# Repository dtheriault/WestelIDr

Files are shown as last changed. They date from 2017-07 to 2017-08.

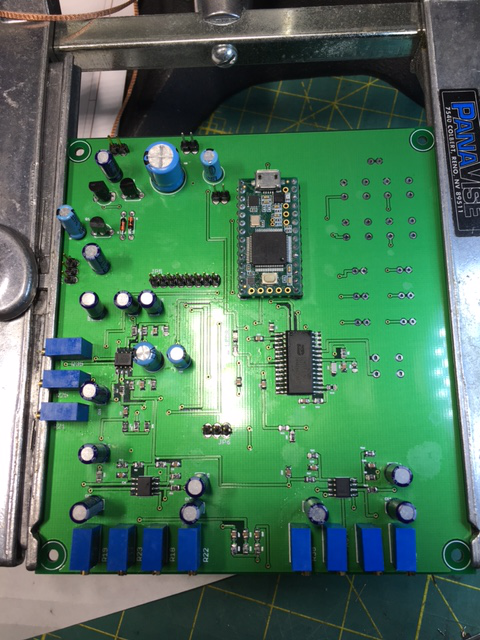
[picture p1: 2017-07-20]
Boards/IMG_1235.JPG

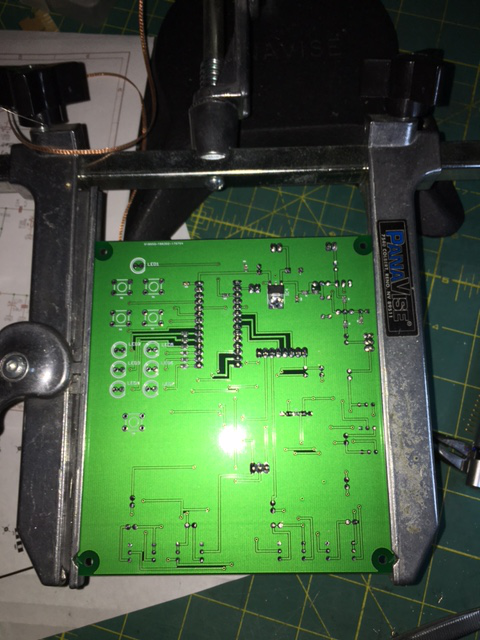
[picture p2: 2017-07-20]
Boards/IMG_1237.JPG

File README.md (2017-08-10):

# WestelIDr
Westel Repeater Controller

This repository contains eagle files and arduino sketch files supporting a repeater
controller based on a Teensy3.2 chip.

The hardware was originally designed to support a Westel DRB25 repeater for WB7NFX
and then updated to support the K7YCA ARES/RACES team who also had one of these
machines.  The controller hardware while supporting the Westel repeater should be
easily modified for other repeater types.  It requires +12v @ approx 150ma, PTT,
Microphone and line audio to generate simple software based carrier detect.

The controller will generate a CW ID or Voice ID in the latest revision of the
sketch file for k7yca.  Can be operated in Ham or Commercial mode with different
timeouts.

Eagle files contain schematics and PCB layout supporting a 3 channel mixer and 3
transistor simplistic audio amplifier to drive a speaker mounted on the Westel
repeater.  There's Gerber files available to spin your own board.

NOTE IMPORTANT:  Current major pin-out issue with the voice ID chip.  I'll update
files and new layout once I fix the darn chip library file.

There's also some mechanical files for a mounting plate for the Westel repeater
which were contributed by Rob KG7LMI.

CW ID code was made possible by SV1DJG and very much appreciated for allowing me to
include his software in the sketch files.

For latest software please refer to the Sketch/k7yca/k7yca.ino file as this version
matches the hardware.  The other two versions were for earlier revisions of the
board for WB7NFX and our Sheriff's Jeep Posse team where I used the controller in
an AmmoCan portable repeater I built for them.

Contact info:

email:  no1d.doug@gmail.com
repository:  https://github.com/dtheriault/WestelIDr

 License:

 Copyright (C) 2017 Douglas Theriault - NO1D

 Software is free software: you can redistribute it and/or modify
 it under the terms of the GNU General Public License as published by
 the Free Software Foundation, either version 3 of the License, or
 (at your option) any later version.

 This is distributed in the hope that it will be useful to someone or ham club/group,
 but WITHOUT ANY WARRANTY; without even the implied warranty of MERCHANTABILITY
 or FITNESS FOR A PARTICULAR PURPOSE.  See the GNU General Public License for
 more details.

 You should have received a copy of the GNU General Public License
 in the repository.  If not, see <http://www.gnu.org/licenses/>.

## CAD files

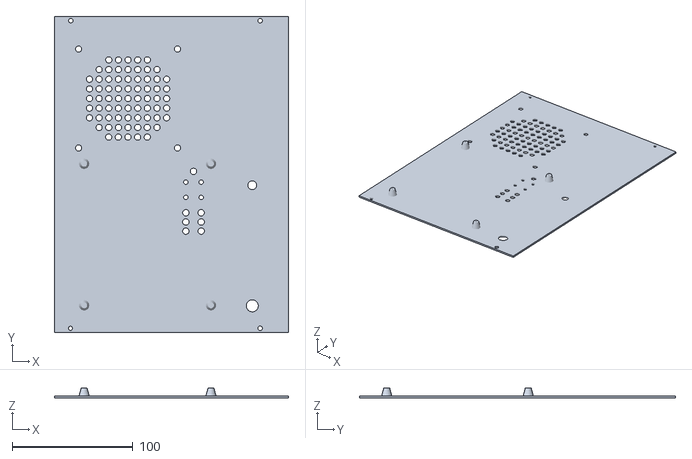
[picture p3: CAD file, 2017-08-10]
Faceplate/westel faceplate 0.9.4.stl
194.0 x 262.0 x 8.00

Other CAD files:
Faceplate/westel faceplate 0.9.4.skp

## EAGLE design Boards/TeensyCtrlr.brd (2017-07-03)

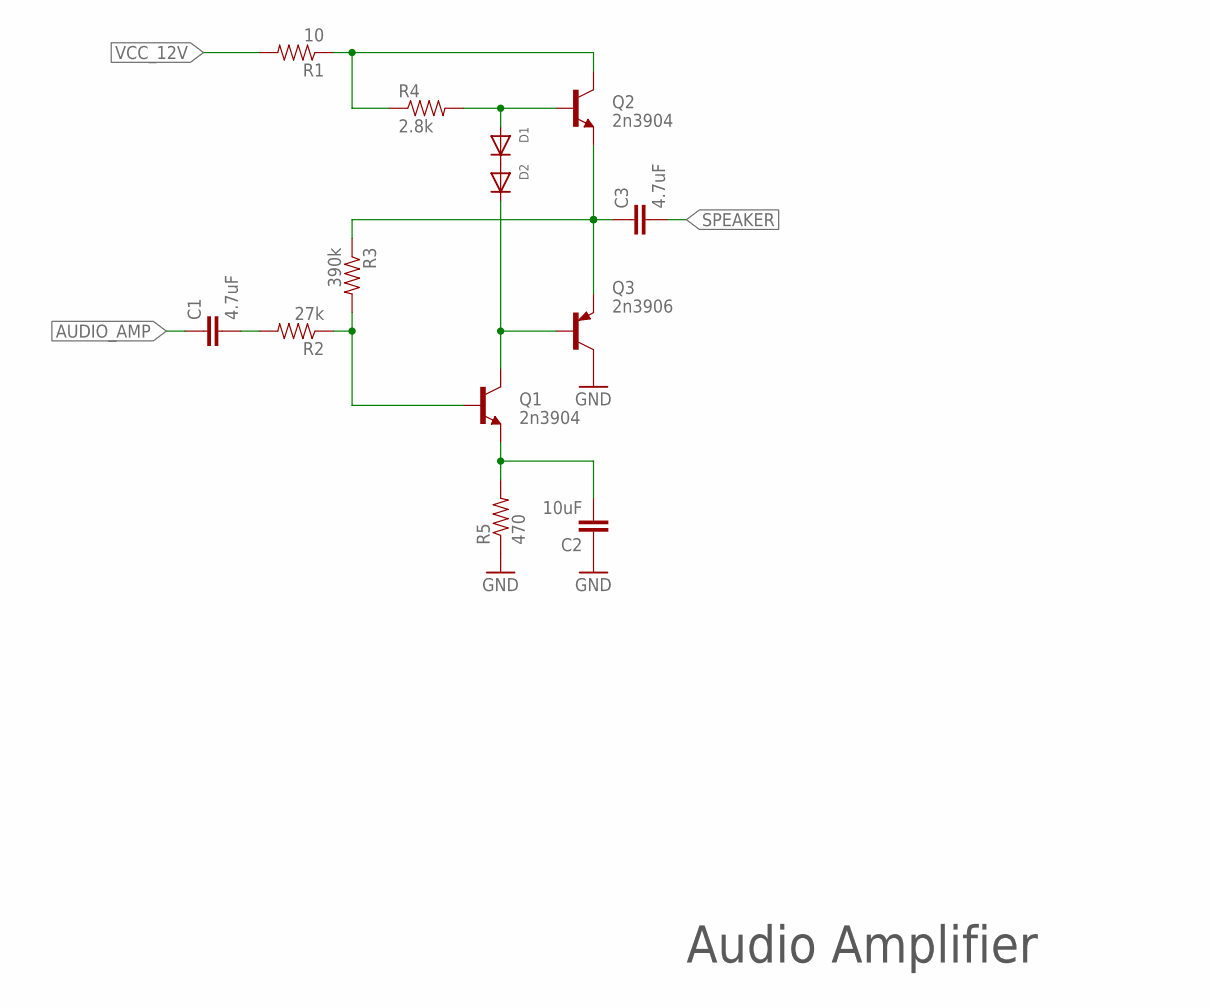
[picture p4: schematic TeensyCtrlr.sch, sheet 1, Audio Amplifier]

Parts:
C1, C3: 4.7uF; CAP-PTH-SMALL
C2: 10uF; CAP-PTH-SMALL
D1, D2: DIODEDO-1N4148; DO-1N4148
Q1, Q2: 2n3904; TO-92-AMMO
Q3: 2n3906; TO92-EBC
R1: 10; 0805
R2: 27k; 0805
R3: 390k; 0805
R4: 2.8k; 0805
R5: 470; 0805

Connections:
AUDIO_AMP: C1.1; also elsewhere on the board
GND: C2.1, Q3.C, R5.1; also elsewhere on the board
unnamed: C1.2, R2.2
unnamed: Q2.3 (C), R1.1, R4.1
unnamed: C2.2, Q1.1 (E), R5.2
unnamed: C3.1, Q2.1 (E), Q3.E, R3.1
unnamed: D1.C, D2.A
unnamed: D1.A, Q2.2 (B), R4.2
unnamed: D2.C, Q1.3 (C), Q3.B
unnamed: Q1.2 (B), R2.1, R3.2
SPEAKER: C3.2; also elsewhere on the board
VCC_12V: R1.2; also elsewhere on the board

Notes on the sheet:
Audio Amplifier

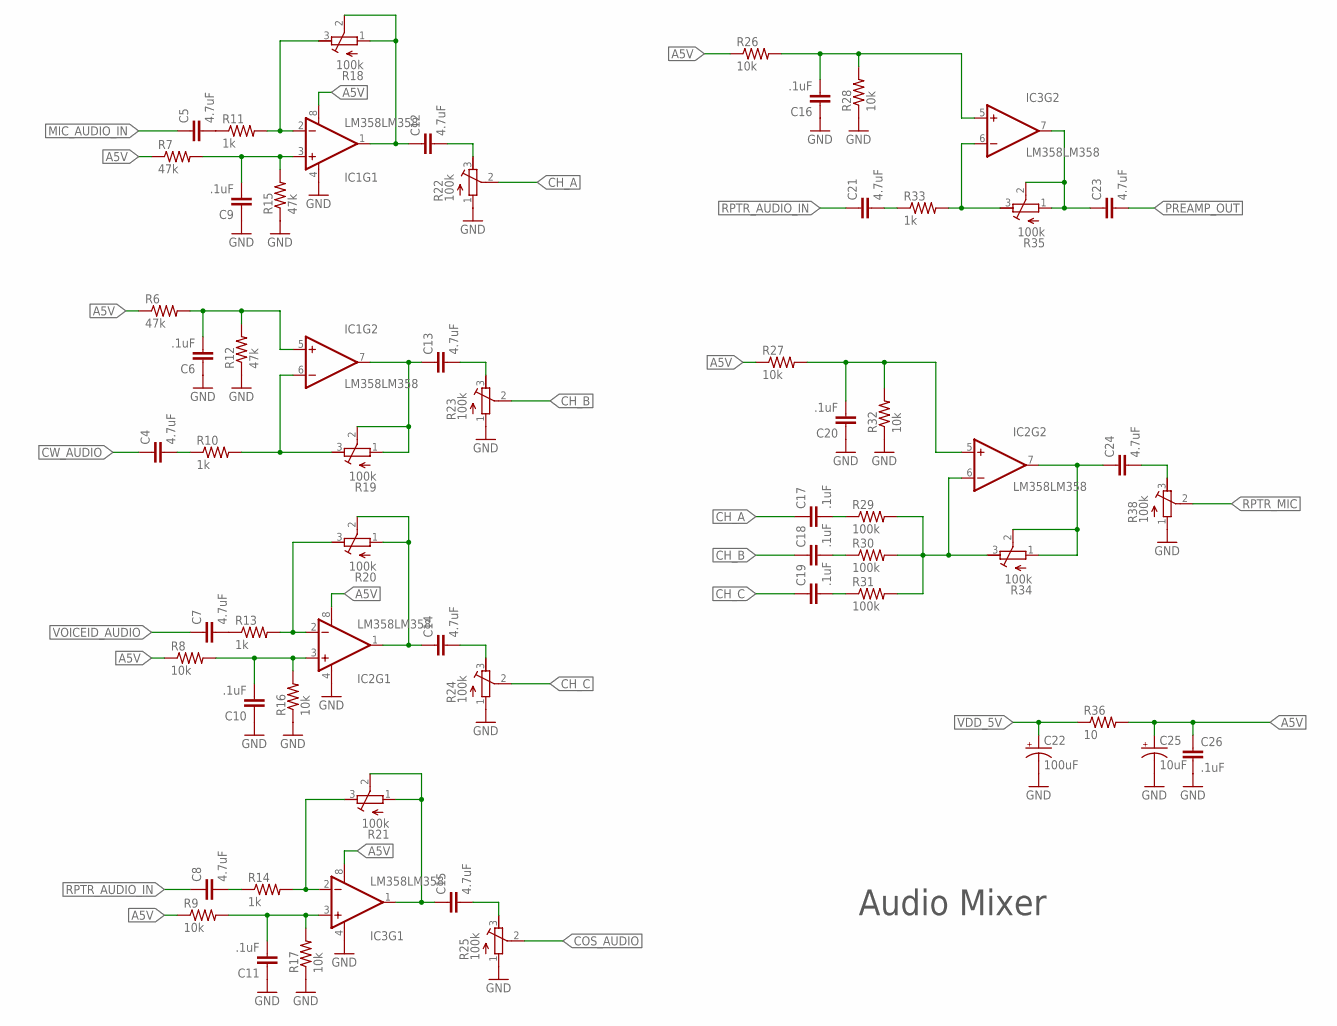
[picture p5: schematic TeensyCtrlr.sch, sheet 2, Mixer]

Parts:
C4, C5, C7, C8, C12, C13, C14, C15, C21, C23, C24: 4.7uF; CAP-PTH-SMALL2
C6, C9, C10, C11, C16, C17, C18, C19, C20, C26: .1uF; 0805
C22: 100uF; CPOL-RADIAL-10UF-25V
C25: 10uF; CPOL-RADIAL-100UF-25V
IC1, IC2, IC3: LM358LM358; SOIC8
R6, R7, R12, R15: 47k; 0805
R8, R9, R16, R17, R26, R27, R28, R32: 10k; 0805
R10, R11, R13, R14, R33: 1k; 0805
R18, R19, R20, R21, R22, R23, R24, R25, R34, R35, R38: 100k; RTRIM3296X
R29, R30, R31: 100k; 0805
R36: 10; 0805

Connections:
A5V: C25.1 (+), C26.1, IC1.8 (V+), IC2.8 (V+), IC3.8 (V+), R6.1, R7.1, R8.1, R9.1, R26.1, R27.1, R36.2
CH_A: C17.1, R22.2 (S)
CH_B: C18.1, R23.2 (S)
CH_C: C19.1, R24.2 (S)
COS_AUDIO: R25.2 (S); also elsewhere on the board
CW_AUDIO: C4.1; also elsewhere on the board
GND: C6.1, C9.1, C10.1, C11.1, C16.1, C20.1, C22.2 (-), C25.2 (-), C26.2, IC1.4 (V-), IC2.4 (V-), IC3.4 (V-), R12.1, R15.1, R16.1, R17.1, R22.1 (A), R23.1 (A), R24.1 (A), R25.1 (A), R28.1, R32.1, R38.1 (A); also elsewhere on the board
MIC_AUDIO_IN: C5.1; also elsewhere on the board
unnamed: IC1.2 (-IN), R11.2, R18.3 (E)
unnamed: C9.2, IC1.3 (+IN), R7.2, R15.2
unnamed: C5.2, R11.1
unnamed: C12.1, IC1.1 (OUT), R18.1 (A), R18.2 (S)
unnamed: C12.2, R22.3 (E)
unnamed: IC1.6 (-IN), R10.2, R19.3 (E)
unnamed: C6.2, IC1.5 (+IN), R6.2, R12.2
unnamed: C4.2, R10.1
unnamed: C13.1, IC1.7 (OUT), R19.1 (A), R19.2 (S)
unnamed: C13.2, R23.3 (E)
unnamed: IC2.2 (-IN), R13.2, R20.3 (E)
unnamed: C10.2, IC2.3 (+IN), R8.2, R16.2
unnamed: C7.2, R13.1
unnamed: C14.1, IC2.1 (OUT), R20.1 (A), R20.2 (S)
unnamed: C14.2, R24.3 (E)
unnamed: IC2.6 (-IN), R29.2, R30.2, R31.2, R34.3 (E)
unnamed: C20.2, IC2.5 (+IN), R27.2, R32.2
unnamed: C24.1, IC2.7 (OUT), R34.1 (A), R34.2 (S)
unnamed: C24.2, R38.3 (E)
unnamed: IC3.2 (-IN), R14.2, R21.3 (E)
unnamed: C11.2, IC3.3 (+IN), R9.2, R17.2
unnamed: C8.2, R14.1
unnamed: C15.1, IC3.1 (OUT), R21.1 (A), R21.2 (S)
unnamed: C15.2, R25.3 (E)
unnamed: IC3.6 (-IN), R33.2, R35.3 (E)
unnamed: C16.2, IC3.5 (+IN), R26.2, R28.2
unnamed: C21.2, R33.1
unnamed: C23.1, IC3.7 (OUT), R35.1 (A), R35.2 (S)
unnamed: C17.2, R29.1
unnamed: C18.2, R30.1
unnamed: C19.2, R31.1
PREAMP_OUT: C23.2; also elsewhere on the board
RPTR_AUDIO_IN: C8.1, C21.1; also elsewhere on the board
RPTR_MIC: R38.2 (S); also elsewhere on the board
VDD_5V: C22.1 (+), R36.1; also elsewhere on the board
VOICEID_AUDIO: C7.1; also elsewhere on the board

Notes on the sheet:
Audio Mixer

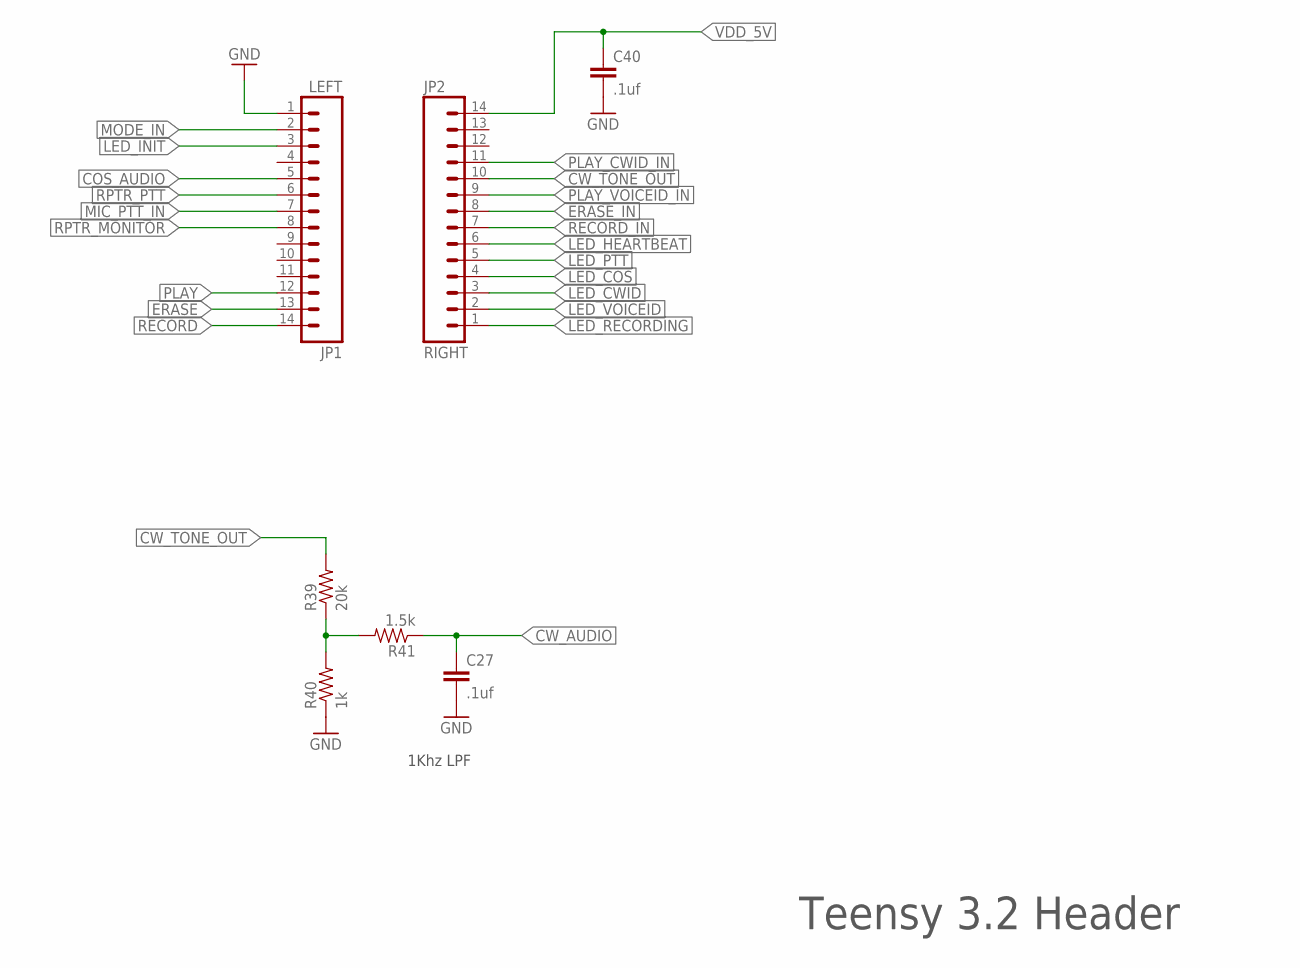
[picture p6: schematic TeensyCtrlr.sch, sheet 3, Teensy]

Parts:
C27, C40: .1uf; 0805
JP1: LEFT; 1X14-LONGPADS
JP2: RIGHT; 1X14-LONGPADS
R39: 20k; 0805
R40: 1k; 0805
R41: 1.5k; 0805

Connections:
COS_AUDIO: JP1.5; also elsewhere on the board
CW_AUDIO: C27.1, R41.1; also elsewhere on the board
CW_TONE_OUT: JP2.10, R39.2
ERASE: JP1.13; also elsewhere on the board
ERASE_IN: JP2.8; also elsewhere on the board
GND: C27.2, C40.2, JP1.1, R40.1; also elsewhere on the board
LED_COS: JP2.4; also elsewhere on the board
LED_CWID: JP2.3; also elsewhere on the board
LED_HEARTBEAT: JP2.6; also elsewhere on the board
LED_INIT: JP1.3; also elsewhere on the board
LED_PTT: JP2.5; also elsewhere on the board
LED_RECORDING: JP2.1; also elsewhere on the board
LED_VOICEID: JP2.2; also elsewhere on the board
MIC_PTT_IN: JP1.7; also elsewhere on the board
MODE_IN: JP1.2; also elsewhere on the board
unnamed: R39.1, R40.2, R41.2
PLAY: JP1.12; also elsewhere on the board
PLAY_CWID_IN: JP2.11; also elsewhere on the board
PLAY_VOICEID_IN: JP2.9; also elsewhere on the board
RECORD: JP1.14; also elsewhere on the board
RECORD_IN: JP2.7; also elsewhere on the board
RPTR_MONITOR: JP1.8; also elsewhere on the board
RPTR_PTT: JP1.6; also elsewhere on the board
VDD_5V: C40.1, JP2.14; also elsewhere on the board

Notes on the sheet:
Teensy 3.2 Header
1Khz LPF

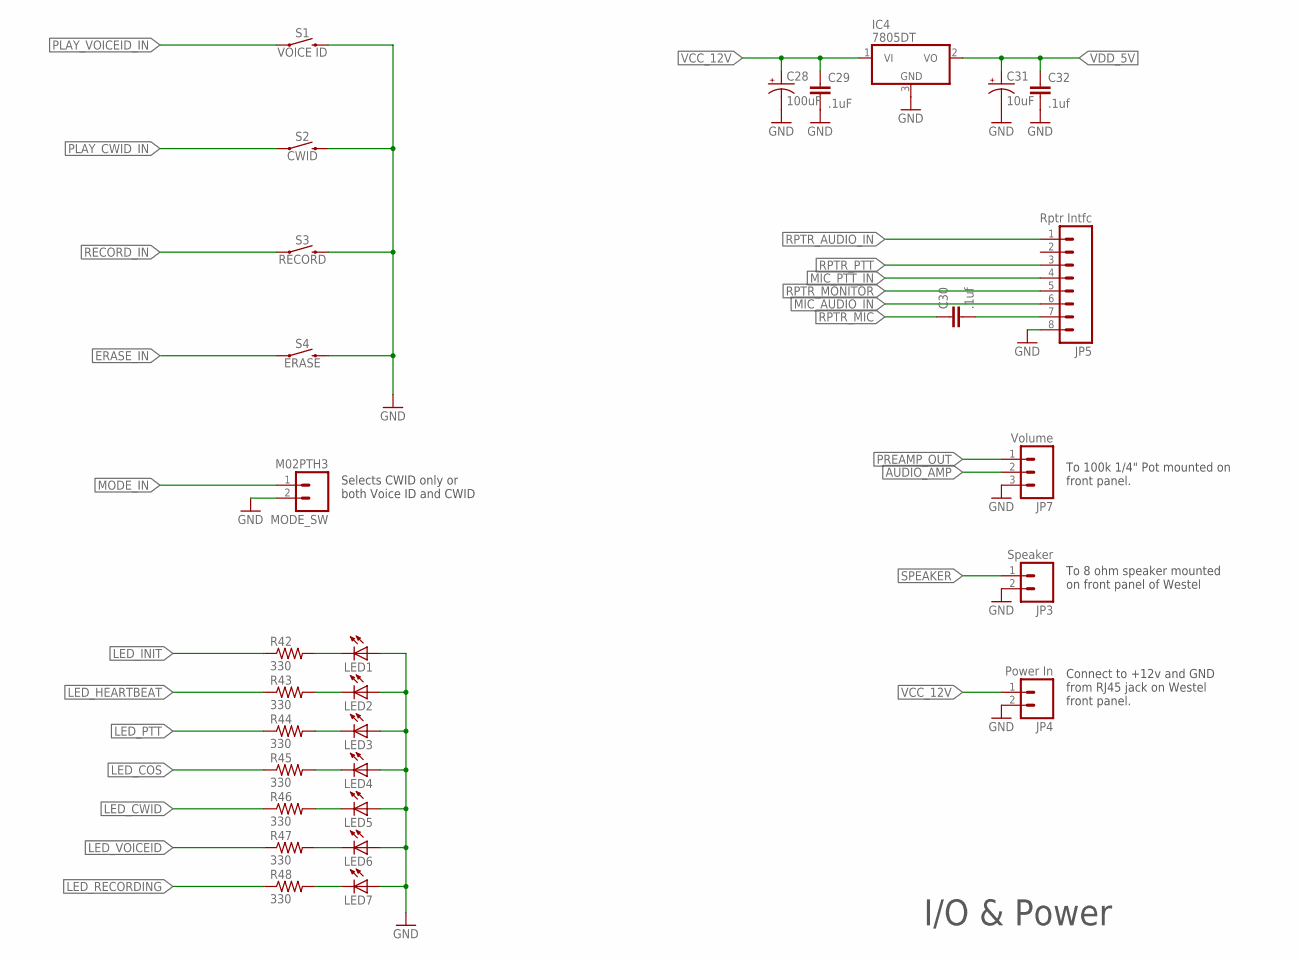
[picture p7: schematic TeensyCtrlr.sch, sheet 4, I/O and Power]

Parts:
C28: 100uF; CPOL-RADIAL-1000UF-25V
C29: .1uF; 0805
C30, C32: .1uf; 0805
C31: 10uF; CPOL-RADIAL-100UF-25V
IC4: 7805DT; TO252
JP3: Speaker; 1X02_LONGPADS
JP4: Power In; 1X02_LONGPADS
JP5: Rptr Intfc; 1X08_LONGPADS
JP7: Volume; 1X03_LONGPADS
LED1, LED2, LED3, LED4, LED5, LED6, LED7: LED5MM
MODE_SW: M02PTH3; 1X02_LONGPADS
R42, R43, R44, R45, R46, R47, R48: 330; 0805
S1: VOICE ID; TACTILE_SWITCH_PTH_6.0MM
S2: CWID; TACTILE_SWITCH_PTH_6.0MM
S3: RECORD; TACTILE_SWITCH_PTH_6.0MM
S4: ERASE; TACTILE_SWITCH_PTH_6.0MM

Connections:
AUDIO_AMP: JP7.2; also elsewhere on the board
ERASE_IN: S4.1; also elsewhere on the board
GND: C28.-, C29.2, C31.2 (-), C32.2, IC4.3 (GND), JP3.2, JP4.2, JP5.8, JP7.3, LED1.A, LED2.A, LED3.A, LED4.A, LED5.A, LED6.A, LED7.A, MODE_SW.2, S1.3 (2), S2.3 (2), S3.3 (2), S4.3 (2); also elsewhere on the board
LED_COS: R45.1; also elsewhere on the board
LED_CWID: R46.1; also elsewhere on the board
LED_HEARTBEAT: R43.1; also elsewhere on the board
LED_INIT: R42.1; also elsewhere on the board
LED_PTT: R44.1; also elsewhere on the board
LED_RECORDING: R48.1; also elsewhere on the board
LED_VOICEID: R47.1; also elsewhere on the board
MIC_AUDIO_IN: JP5.6; also elsewhere on the board
MIC_PTT_IN: JP5.4; also elsewhere on the board
MODE_IN: MODE_SW.1; also elsewhere on the board
unnamed: LED1.K (C), R42.2
unnamed: LED2.K (C), R43.2
unnamed: LED3.K (C), R44.2
unnamed: LED4.K (C), R45.2
unnamed: LED5.K (C), R46.2
unnamed: LED6.K (C), R47.2
unnamed: LED7.K (C), R48.2
unnamed: C30.2, JP5.7
PLAY_CWID_IN: S2.1; also elsewhere on the board
PLAY_VOICEID_IN: S1.1; also elsewhere on the board
PREAMP_OUT: JP7.1; also elsewhere on the board
RECORD_IN: S3.1; also elsewhere on the board
RPTR_AUDIO_IN: JP5.1; also elsewhere on the board
RPTR_MIC: C30.1; also elsewhere on the board
RPTR_MONITOR: JP5.5; also elsewhere on the board
RPTR_PTT: JP5.3; also elsewhere on the board
SPEAKER: JP3.1; also elsewhere on the board
VCC_12V: C28.+, C29.1, IC4.1 (VI), JP4.1; also elsewhere on the board
VDD_5V: C31.1 (+), C32.1, IC4.2 (VO); also elsewhere on the board

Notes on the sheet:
I/O & Power
To 100k 1/4" Pot mounted on front panel.
To 8 ohm speaker mounted on front panel of Westel
Connect to +12v and GND from RJ45 jack on Westel front panel.
Selects CWID only or both Voice ID and CWID

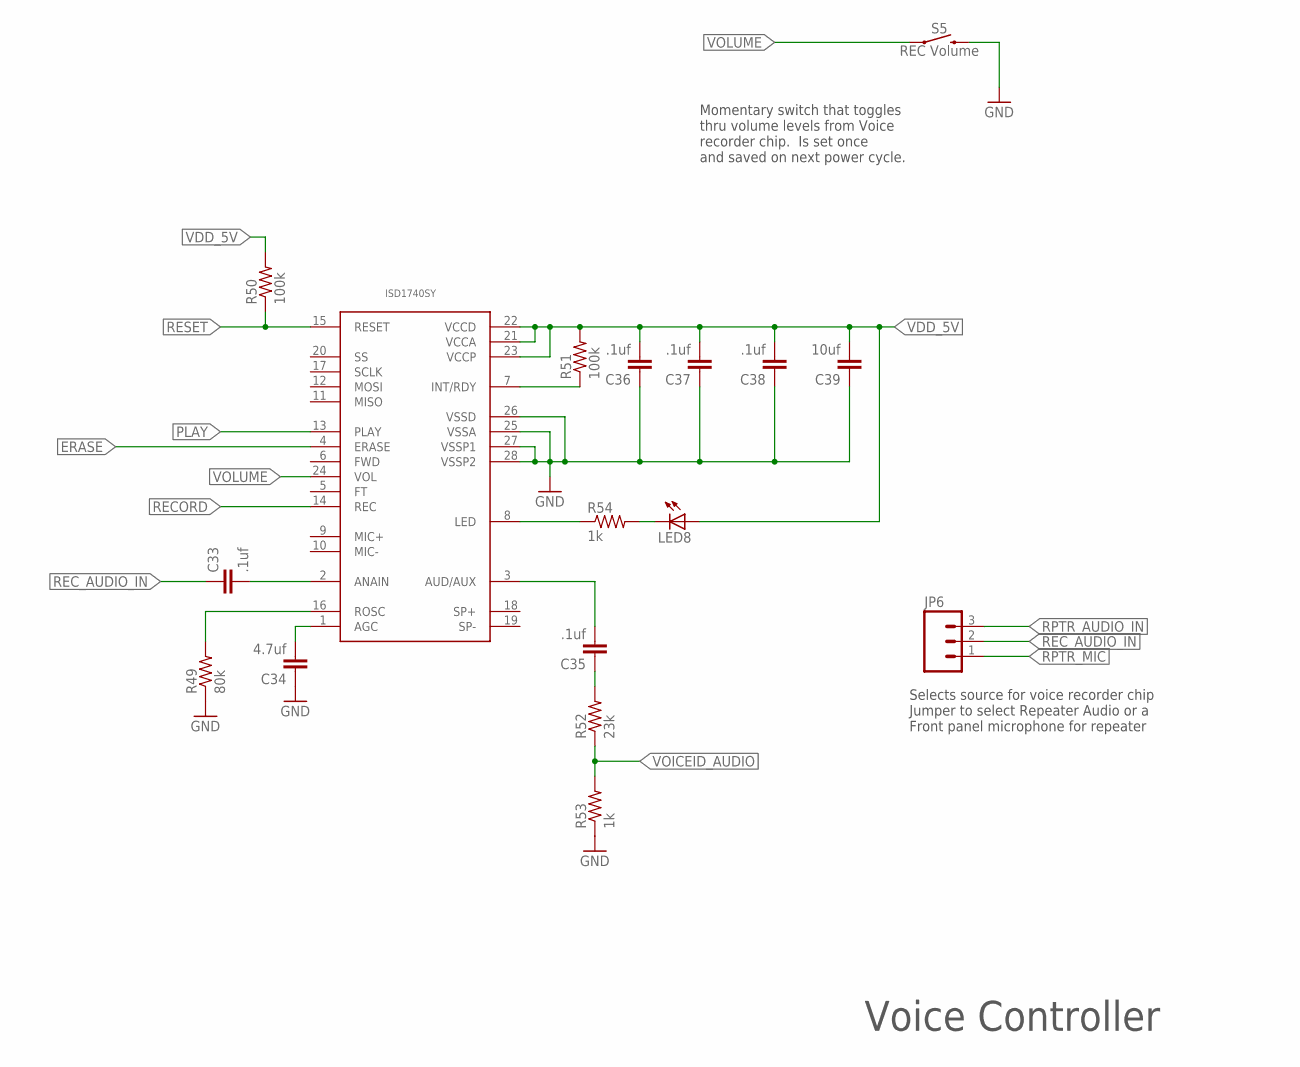
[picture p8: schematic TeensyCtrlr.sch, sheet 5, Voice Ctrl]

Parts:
C33, C35, C36, C37, C38: .1uf; 0805
C34: 4.7uf; 0805
C39: 10uf; 0805
IC$1: ISD1740SYSOIC28; SOIC-28
JP6: M03LONGPADS; 1X03_LONGPADS
LED8: LEDCHIP-LED0805; CHIP-LED0805
R49: 80k; 0805
R50, R51: 100k; 0805
R52: 23k; 0805
R53, R54: 1k; 0805
S5: REC Volume; TACTILE_SWITCH_PTH_6.0MM

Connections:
ERASE: IC$1.4 (ERASE); also elsewhere on the board
GND: C34.1, C36.1, C37.1, C38.1, C39.1, IC$1.25 (VSSA), IC$1.26 (VSSD), IC$1.27 (VSSP1), IC$1.28 (VSSP2), R49.1, R53.1, S5.3 (2); also elsewhere on the board
unnamed: C33.2, IC$1.2 (ANAIN)
unnamed: C35.2, IC$1.3 (AUD/AUX)
unnamed: C35.1, R52.2
unnamed: C34.2, IC$1.1 (AGC)
unnamed: IC$1.16 (ROSC), R49.2
unnamed: IC$1.7 (INT/RDY), R51.1
unnamed: IC$1.8 (LED), R54.1
unnamed: LED8.C, R54.2
PLAY: IC$1.13 (PLAY); also elsewhere on the board
RECORD: IC$1.14 (REC); also elsewhere on the board
REC_AUDIO_IN: C33.1, JP6.2
RESET: IC$1.15 (RESET), R50.1
RPTR_AUDIO_IN: JP6.3; also elsewhere on the board
RPTR_MIC: JP6.1; also elsewhere on the board
VDD_5V: C36.2, C37.2, C38.2, C39.2, IC$1.21 (VCCA), IC$1.22 (VCCD), IC$1.23 (VCCP), LED8.A, R50.2, R51.2; also elsewhere on the board
VOICEID_AUDIO: R52.1, R53.2; also elsewhere on the board
VOLUME: IC$1.24 (VOL), S5.1

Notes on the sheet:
Voice Controller
Selects source for voice recorder chip Jumper to select Repeater Audio or a Front panel microphone for repeater
Momentary switch that toggles thru volume levels from Voice recorder chip. Is set once and saved on next power cycle.

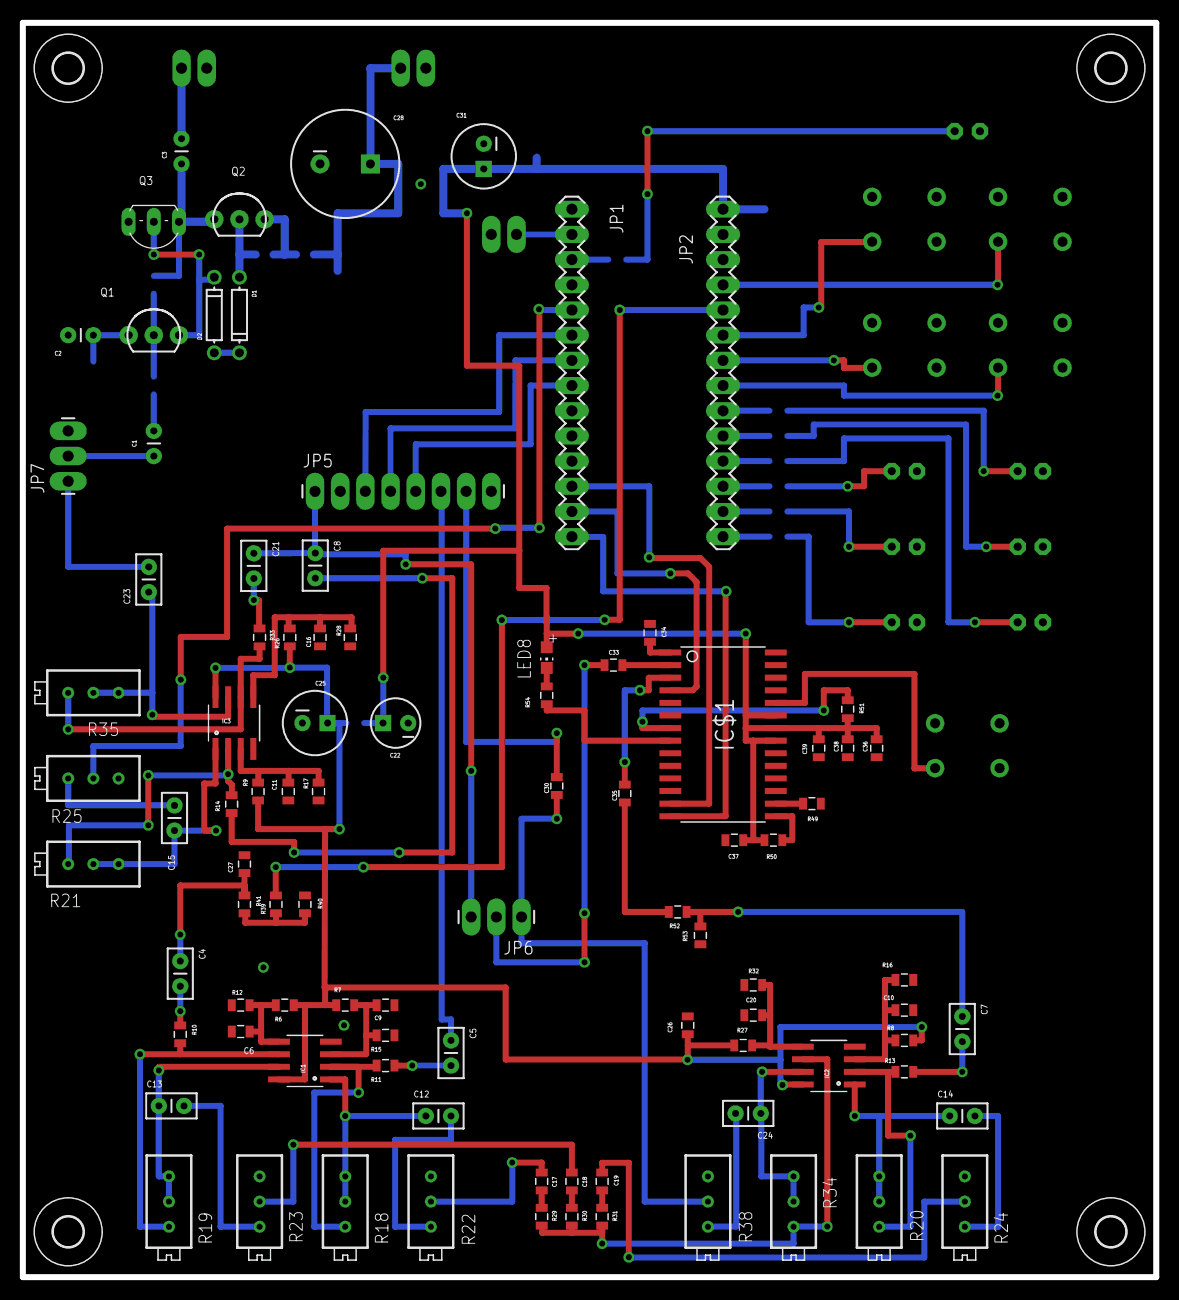
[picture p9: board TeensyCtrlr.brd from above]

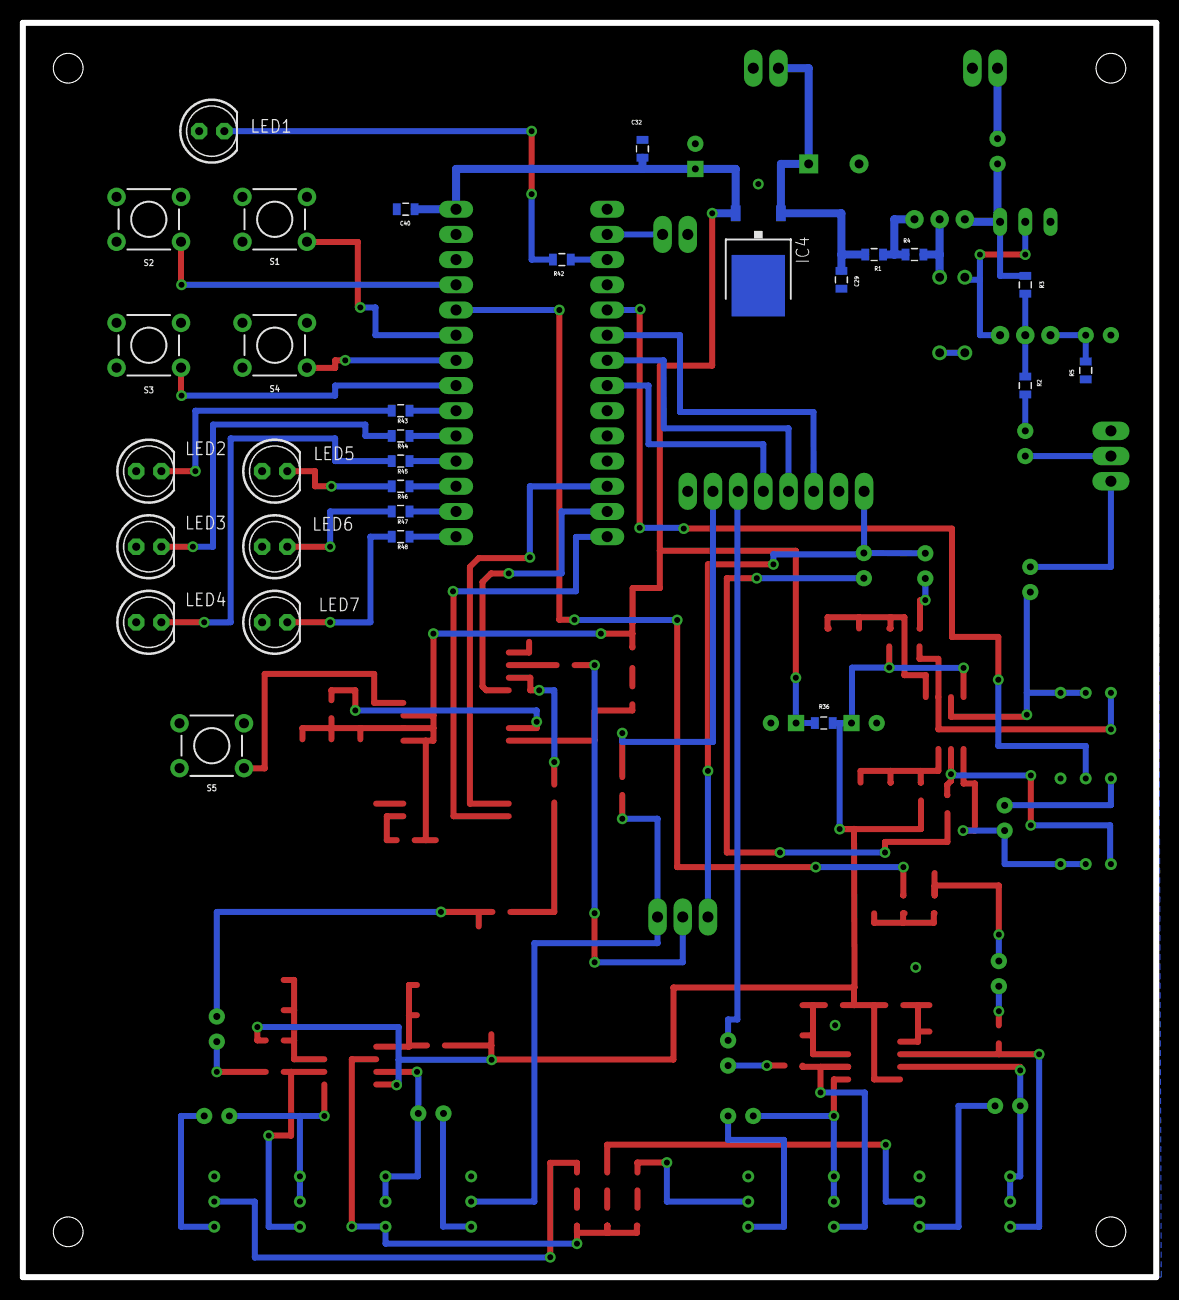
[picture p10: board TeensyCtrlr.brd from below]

Board: 2 copper layers, 114.3 x 126.5 mm, 128 parts (29 on the bottom side), 94 nets.

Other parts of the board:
U$1, U$2, U$3, U$4: 3,0

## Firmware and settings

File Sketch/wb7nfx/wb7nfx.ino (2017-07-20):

//
// File: TeensyRptrCtrlr.ino
//
// Author:  NO1D - Doug Theriault
// Dated:   20170112
//
// Description:
//
// This sketch is a very basic/simple repeater ID controller which was developed
// for WB7NFX.  The interface is to a Westel DRB25 VHF repeater however this
// software is generic and can be modified to fit other requirements.
//
// The software handles button presses to activate CW ID, Voice ID and record
// and erase functions and mode switch.  In addition it outputs series of 7 LEDs
// to track state/function.  It also outputs control lines to a Voice ID board
// and the repeater itself.
//
// Since the Westel Repeater did not have means to detect COS (carrier operated
// squelch) the repeaters audio is fed into a pin configured with ADC so its
// voltage can be read.
//
// The controller was based on Teensy3.2 board.  I started with an ATiny85 but
// quickly ran out of pins as I wanted to add more/more features...
//
// References:
//
// The CW ID portion of the code was developed by SV1DJG which was a great start
// for me to get something working on an ATiny85 chip.  Special thanks goes out
// to Nick for producing this software.  I include his file header below.
//
// Bugs/Issues/ToDo:
//
// Ideally this would all be run off interrupts/timers.  Someday perhaps.
// This is not a very powerful repeater controller.  While it will ID per part 97
// rules, its been deployed only recently and may still contain bugs.
// There are some printf statements for debugging left in the code and do affect
// accuracy of the timing.  You might need to modify delay loops when removing
// them.
//
// Hardware:
//
// Schematic for simple 3-channel audio mixer, 3-transistor audio amp, Teensy I/O
// LED's etc are available on github.
//
// Voice ID is handled by external board similar to:
//   https://ludens.cl/Electron/voiceID/voiceID.html
//
// Contact info:
//
// email:  no1d.doug@gmail.com
// repository:  https://github.com/dtheriault/TeensyRptrCtrlr
//
// License:
//
// Copyright (C) 2017 Douglas Theriault - NO1D
//
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
//
////////////////////////////////////////////////
//
// A simple CW Blinker (aka LED Beacon)
// by SV1DJG (c.2016)
//
// This is a ultra simple blinker in CW for the 
// digispark mini board (attiny85).
// change the led port if using a different
// board (e.g. Arduino)
//
// Just set your message into the msg array and you 
// are ready to go.Make sure to use ONLY the set
// of the supported characters.
// the supported set of characters is capital 
// letters,numbers and a few symbols.
//
// You can also modify the transmission speed by 
// changing the speedWPM variable.
//
// HAVE FUN!!
// 
// This code is provided as-is and may contain bugs!
//
// (codesize:1132 bytes + message length)
//
////////////////////////////////////////////////

#include <avr/pgmspace.h>

//
// PIN Definitions:  Input and Outputs
//
#define PLAY_VOICE_IN  1          // Send the Voice ID, Play on Voice Bd
#define PLAY_CW_IN     2          // Send a CW ID from the Teensy
#define ERASE_IN       3          // Erase the Voice ID, Erase on Voice Bd
#define RECORD_IN      4          // Record New Voice ID, Record on Voice Bd
#define MODE_IN        5          // Toggle switch for CW only or CW & Voice ID
//
#define LED_INIT       6          // Setup has been executed, stays lit
#define LED_HEARTBEAT  7          // Loop interval, one second pulse
#define LED_PTT        8          // PTT is activated, Microphone front panel
#define LED_COS        9          // COS detected from Repeater Audio feed
#define LED_CWID      10          // CW ID in process
#define LED_VOICEID   11          // Voice ID in process
#define LED_RECORDING 12          // Recording new Voice ID in process
//
#define RPTR_MONITOR  14          // Repeater Monitor Active Low (not used)
#define PTT_IN        15          // Front Panel Microphone, Active Low
//
#define RECORD_OUT    18          // Button on Voice Bd
#define ERASE_OUT     19          // Button on Voice Bd
#define PLAY_OUT      20          // Button on Voice Bd
//
#define CW_AUDIO      21          // PWM Teensy output of CW Audio tone
#define PTT_OUT       22          // PTT to Repeater, Active Low
#define COS_IN        23          // Carrier Detect Input
//
//
// 
// General Defines
//
#define CW_TONE      750          // CW ID Tone in Hertz
//
#define MODE_CW_ONLY   0          // Does not play Voice ID
#define MODE_BOTH      1          // Plays both Voice and CW ID's
//
// State Machine Defines
//
#define IDLE              1       // IDLE State
#define TIMING_CW         2       // Timer State:  Detected COS/PTT
#define TIMING_VOICE      3       // Timer State:  Detected COS/PTT
#define CWID              4       // CW ID: Send CW ID now, timer expired
#define VOICEID           5       // Voice ID:  Send Voice ID
#define RPTR_ACTIVE       6       // Time COS/PTT been active
#define ID_FIRST          7       // First ID > 10m on first PTT/COS from IDLE period
//
// Timeouts are in seconds
//
#define CW_TIMEOUT    600         // Play CW ID every 10m after COS or PTT go active
#define VOICE_TIMEOUT 1800        // Play Voice ID every 30m when IDLE
#define COS_TIMEOUT   300         // COS/PTT 3m timeout
#define VID_TIMEOUT   1200        // 20m after CWID, if we're idle, we VoiceID
//
// All delays are in ms
//
#define RECORDING_DELAY 8000      // Record for 8s
#define ERASE_DELAY     10000     // Erase for 10s
#define VOICEID_DELAY   7000      // 7s for voice id to play
#define PTT_DELAY       750       // 1.5s PTT delay 
#define COS_DELAY       100       // delay 100ms between consecutive COS ADC reads
//
#define LED_OFF      LOW
#define LED_ON      HIGH

#define TRUE           0
#define FALSE          1

// this defines the keying level and provides a quick way to change the keying method. 
// when we use a LED we need HIGH to turn the LED on and LOW to turn the LED off
// but if we select to connect an external switching hardware , this may need to be reversed
#define MORSE_KEY_DOWN  HIGH
#define MORSE_KEY_UP    LOW

// delay before repeating the message (in Ms)
#define repeatDelayMs 300000

// transmission speed (in words per minute)
#define speedWPM 18

// element duration is according to Farnsworth Technique
// see : http://www.arrl.org/files/file/Technology/x9004008.pdf
#define dotDuration  1200 / speedWPM          // element duration in milliseconds
#define dashDuration        dotDuration * 3

#define interSymbolDuration dotDuration
#define interCharDuration   dotDuration * 3
#define interWordDuration   dotDuration * 7


//
// Global Variables Here
//
boolean mic_ptt;
boolean play_voice;
boolean play_cw;
boolean erase_voice;
boolean record;
boolean voice_bd_reset;

int mode;
int state;
int last_state;

int cw_timer;
int voice_timer;
int activity_timer;
int last_id;

int cos_in;

boolean last_ptt;
boolean last_cos;

char dState[8][16] =
  {
    "UNKNOWN",
    "IDLE",
    "TIMING CW",
    "TIMING VOICE",
    "CW ID",
    "VOICE ID",
    "RPTR ACTIVE",
    "ID FIRST"
  };
    
//////////////////////////////////////////////////////////////////////////////////////////////
//
// this is the beacon message (only capital letters, numbers and a few symbols - see below)
//
//////////////////////////////////////////////////////////////////////////////////////////////

//char const msg[] = "TEST DE SV1DJG";
char const msg[] = "DE WB7NFX/R";
char const msgTimeout[] = "TIMEOUT";

//
// Morse code table
// ----------------
// Morse code elements are variable length and transmitted Msb first.
// we need to know the length of each element so we save
// it along with the element as the first part of the pair in the table.
//
// Each element is made up from 1's and 0's where:
// 1 means DOT
// 0 mean DASH
// for example, A is DOT-DASH which is translated to 10.
// B is DASH-DOT-DOT-DOT which is translated to 0111 etc.
// these are encoded as binary values and paired with their length
// for example 
//    A -> 2,B10 
//    B -> 4,B0111
// etc
//
// table of elements for Morse cose numbers do not follow this as all elements are 5 digits long
// (so we save space in the symbol table)
//
byte const letters[] PROGMEM =
{ 
  2,B10,   // A
  4,B0111, // B
  4,B0101, // C
  3,B011,  // D
  1,B1,    // E
  4,B1101, // F
  3,B001,  // G
  4,B1111, // H
  2,B11,   // I
  4,B1000, // J
  3,B010,  // K
  4,B1011, // L
  2,B00,   // M
  2,B01,   // N
  3,B000,  // O
  4,B1001, // P
  4,B0010, // Q
  3,B101,  // R
  3,B111,  // S
  1,B0,    // T
  3,B110,  // U
  4,B1110, // V
  3,B100,  // W
  4,B0110, // X
  4,B0100, // Y
  4,B0011, // Z
};

byte const numbers[] PROGMEM =
{ 
  B00000, // 0
  B10000, // 1
  B11000, // 2
  B11100, // 3
  B11110, // 4
  B11111, // 5
  B01111, // 6
  B00111, // 7
  B00011, // 8
  B00001, // 9
};


byte const symbols[] PROGMEM =
{ 
  6,B101010,  // Full-stop (period)
  6,B001100,  // Comma
  6,B110011,  // Question mark (query)
  5,B01101 ,  // Slash
  5,B01110 ,  // Equals sign
};

// transmits a morse element (either a dot or a dash)
void sendSymbol(boolean sendDot)
{
  digitalWrite(LED_CWID, MORSE_KEY_DOWN);
  tone(CW_AUDIO, CW_TONE);
  delay(sendDot ? dotDuration : dashDuration); 
  digitalWrite(LED_CWID, MORSE_KEY_UP);
  noTone(CW_AUDIO);
}

// transmits an ASCII character in Morse Code
void sendCharacter(char c)
{
  byte numberOfBits = 0;
  byte elementCode  = 0;
  
  if (c >= 'A' && c <='Z')
  {
    int elementIndex = (int)(c-'A');
    numberOfBits = pgm_read_byte(&letters[elementIndex * 2]);
    elementCode  = pgm_read_byte(&letters[elementIndex * 2 + 1]);
  }
  else if (c >= '0' && c <='9')
  {
    int elementIndex = (int)(c-'0');
    numberOfBits = 5;
    elementCode  = pgm_read_byte(&numbers[elementIndex]);
  }
  else if (c == ' ')
  {
    // adjust delay because we have already "waited" for a character separation duration
    // NOTE:this delay will not be 100% accurate if the first character in the message is SPACE
    delay(interWordDuration-interCharDuration); 
  }
  else
  {
    int elementIndex = -1;

    if (c == '.')      elementIndex = 0;
    else if (c == ',') elementIndex = 1;
    else if (c == '?') elementIndex = 2;
    else if (c == '/') elementIndex = 3;
    else if (c == '=') elementIndex = 4;
   
    if (elementIndex != -1)
    {
      numberOfBits = pgm_read_byte(&symbols[elementIndex * 2]);
      elementCode  = pgm_read_byte(&symbols[elementIndex * 2 + 1]);
    }
  }
  
  
  if (numberOfBits > 0)
  {
    byte mask = 0x01 << (numberOfBits - 1);
    
    while (numberOfBits > 0 )
    {
      
      sendSymbol((elementCode & mask) == mask);
      delay(interSymbolDuration);
      mask = mask >> 1;
      --numberOfBits;
    }
     // adjust delay because we have already "waited" for a dot duration
     delay(interCharDuration - interSymbolDuration);
   }  
   
}

// transmits an ASCII message in Morse Code
void sendCWID(const char* msg)
{
  // trigger PTT so we send ID over repeater
  digitalWrite(PTT_OUT, LOW);
  digitalWrite(LED_PTT, LED_ON);

  delay(PTT_DELAY);
  
  while (*msg)
    sendCharacter(*msg++);

  delay(PTT_DELAY);

  // turn off PTT at the end
  digitalWrite(PTT_OUT, HIGH);
  digitalWrite(LED_PTT, LED_OFF);
}

// transmits Voice ID via external board
void sendVoiceID()
{
  Serial.print("Sending Voice ID\n");
  digitalWrite(PTT_OUT, LOW);
  digitalWrite(LED_PTT, LED_ON);

  delay(PTT_DELAY);

  digitalWrite(PLAY_OUT, LOW);
  digitalWrite(LED_VOICEID, LED_ON);

  // TODO: Ideally we want program to continue while output is low
  //       as believe voice play stops when we toggle back high

  delay(VOICEID_DELAY);
  
  digitalWrite(PLAY_OUT, HIGH);
  digitalWrite(LED_VOICEID, LED_OFF);

  delay(PTT_DELAY);

  // turn off PTT at the end
  digitalWrite(PTT_OUT, HIGH);
  digitalWrite(LED_PTT, LED_OFF);
  
  Serial.print("End Voice ID\n");
}

//
// Reset the external Voice ID board
//
void resetVoiceBd()
{
  //  digitalWrite(RESET_OUT, LOW);
  delay(500);
  //  digitalWrite(RESET_OUT, HIGH);
}

//
// Erase stored Voice ID
//
void eraseVoice()
{
  digitalWrite(ERASE_OUT, LOW);
  delay(ERASE_DELAY);
  digitalWrite(ERASE_OUT, HIGH);
  Serial.print("Voice ID Erased\n");
}

//
// Record New Voice ID
//
void recordVoiceID()
{
  // Enable recording for max of 7 seconds
  digitalWrite(LED_RECORDING, LED_ON);
  digitalWrite(RECORD_OUT, LOW);

  delay(RECORDING_DELAY);

  digitalWrite(RECORD_OUT, HIGH);
  digitalWrite(LED_RECORDING, LED_OFF);

  Serial.print("Voice ID Recorded\n");
}

//
// readCOS()
//
boolean readCOS()
{
  int rValue = 0;

  rValue = analogRead(COS_IN);
  delay(COS_DELAY);
  rValue += analogRead(COS_IN);

  rValue = rValue/2;
  
  //  Serial.printf("COS: %3d\n", rValue);

  if (rValue > 30) return HIGH;

  return LOW;
}

//
// readInputs()
//
void readInputs()
{

  mic_ptt = digitalRead(PTT_IN);
  play_voice = digitalRead(PLAY_VOICE_IN);
  play_cw = digitalRead(PLAY_CW_IN);
  erase_voice = digitalRead(ERASE_IN);
  record = digitalRead(RECORD_IN);
  mode = digitalRead(MODE_IN);

  cos_in = readCOS();
}


//
// execCommands()
//
void execCommands()
{
  // Low Priority:  Handle Front Panel Buttons
  //
  if (play_cw == LOW) 
      state = CWID;

  else if (play_voice == LOW) 
      state = VOICEID;

  //  if (voice_bd_reset == LOW)
  //      resetVoiceBd();

  if (record == LOW)
      recordVoiceID();

  else if (erase_voice == LOW)
      eraseVoice();

  // Med Priority:  Handle COS input
  // 
  if (cos_in == HIGH) {
    if (last_cos == LOW)
      Serial.print("COS Active\n");
    last_cos = HIGH;
    // light the COS LED
    digitalWrite(LED_COS, LED_ON);
    }
  else {
      if (last_cos == HIGH)
	Serial.print("COS Deactivated\n");
      last_cos = LOW;
      digitalWrite(LED_COS, LED_OFF);
    }

  // High Priority:  Handle PTT
  //
  if (mic_ptt == LOW) {
    if (last_ptt == HIGH) 
      Serial.print("PTT Active\n");
    last_ptt = LOW;
    digitalWrite(LED_PTT, LED_ON);
    digitalWrite(PTT_OUT, LOW);
  }
  else {
    digitalWrite(LED_PTT, LED_OFF);
    digitalWrite(PTT_OUT, HIGH);
    if (last_ptt == LOW)
      Serial.print("PTT Deactivated\n");
    last_ptt = HIGH;
  }

  //  Serial.printf("execCmd:  [COS]: %d, [PTT]: %d\n", cos_in, mic_ptt);
}

//
// Initialization Function - executed once
//
void setup() 
{
  int x = 0;
  int value = 0;
  
  // Initilize Pins
  //
  pinMode(PTT_IN, INPUT_PULLUP);
  pinMode(PLAY_VOICE_IN, INPUT_PULLUP);
  pinMode(PLAY_CW_IN, INPUT_PULLUP);
  pinMode(ERASE_IN, INPUT_PULLUP);
  pinMode(RECORD_IN, INPUT_PULLUP);
  pinMode(MODE_IN, INPUT_PULLUP);

  analogReference(DEFAULT);
  for (x = 0; x < 100; x++) {
    value += analogRead(COS_IN);
  }
  
  pinMode(LED_INIT, OUTPUT);
  pinMode(LED_HEARTBEAT, OUTPUT);
  pinMode(LED_PTT, OUTPUT);
  pinMode(LED_COS, OUTPUT);
  pinMode(LED_CWID, OUTPUT);
  pinMode(LED_VOICEID, OUTPUT);
  pinMode(LED_RECORDING, OUTPUT);

  // pinMode(CW_AUDIO, ????);

  pinMode(PTT_OUT, OUTPUT);
  pinMode(PLAY_OUT, OUTPUT);
  pinMode(RECORD_OUT, OUTPUT);
  pinMode(ERASE_OUT, OUTPUT);
  //  pinMode(RESET_OUT, OUTPUT);
  

  // preset digital outputs
  digitalWrite(PTT_OUT, HIGH);
  digitalWrite(PLAY_OUT, HIGH);
  digitalWrite(RECORD_OUT, HIGH);
  digitalWrite(ERASE_OUT, HIGH);
  
  // Initialize State Machine to IDLE
  //
  state = IDLE;
  last_state = DEFAULT;
  
  // Voice_Bd_Reset the timer counts
  //
  cw_timer = CW_TIMEOUT;
  voice_timer = VOICE_TIMEOUT;
  activity_timer = COS_TIMEOUT;
  last_id = CW_TIMEOUT;
  
  // voice_bd_reset globals
  //
  play_voice = HIGH;
  play_cw = HIGH;
  erase_voice = HIGH;
  record = HIGH;
  mode = MODE_BOTH;
  voice_bd_reset = HIGH;

  // initialize carrier operated squelch
  //
  cos_in = 0;
  mic_ptt = HIGH;

  // initialize states for printing
  //
  last_ptt = HIGH;
  last_cos = LOW;
  
  // Flash LED's during Init
  //
  digitalWrite(LED_INIT, LED_ON);
  digitalWrite(LED_HEARTBEAT, LED_ON);
  digitalWrite(LED_PTT, LED_ON);
  digitalWrite(LED_COS, LED_ON);
  digitalWrite(LED_CWID, LED_ON);
  digitalWrite(LED_VOICEID, LED_ON);
  digitalWrite(LED_RECORDING, LED_ON);

  delay(2000);
  
  digitalWrite(LED_INIT, LED_OFF);
  digitalWrite(LED_HEARTBEAT, LED_OFF);
  digitalWrite(LED_PTT, LED_OFF);
  digitalWrite(LED_COS, LED_OFF);
  digitalWrite(LED_CWID, LED_OFF);
  digitalWrite(LED_VOICEID, LED_OFF);
  digitalWrite(LED_RECORDING, LED_OFF);

  delay(2000);

  // Leave this LED on at end of INIT function
  digitalWrite(LED_INIT, LED_ON);

  Serial.begin(9600);
}

// Main Repeater Controller Loop
//
// Description:
//
// This routine will loop endlessely executing a simple state machine
// that performs necessary ID'ng of the 2m repeater for Part 97 rules.
// When the repeater is idle, every 30m the repeater will key a voice ID
// board to play a Voice ID message.  If from IDLE, the repeater generates
// transmission, Carrier Detect is determined at which time an ID will be 
// sent when PTT is non-active.  Then, 10m later a CW Id will be sent.
//
// The routine calls series of functions to read input from some switches,
// from the PTT and Monitor lines to perform specific actions such as 
// recording a message, playing a Voice or CW Id or erasing a Voice ID.
//
// Note:  Currently the CW Id is burned into the code.  User must keep the
//        voice ID same as CW Id.
//
// See the design document for schematic and details on operational control.
//
void loop() 
{

  // Read Inputs
  readInputs();
  
  // Execute FrontPanel commands
  execCommands();
    
  // Execute State Machine
  switch (state)
    {
    case IDLE:
      last_state = IDLE;
      // reset timeout counters
      cw_timer = CW_TIMEOUT;
      voice_timer = VOICE_TIMEOUT;
      activity_timer = COS_TIMEOUT;
      state = TIMING_VOICE;
      break;

    case TIMING_CW:
      last_state = TIMING_CW;
      if (--cw_timer <= 0)
	state = CWID;
      else if ((mic_ptt == LOW) || (cos_in == HIGH)) {
	state = RPTR_ACTIVE;
	activity_timer = COS_TIMEOUT;
      }
      break;

    case TIMING_VOICE:
      last_state = TIMING_VOICE;
      // if we've timed out, immediately send appropriate ID
      if (--voice_timer <= 0) {
	  if (mode == MODE_BOTH)
	    state = VOICEID;
	  else
	    state = IDLE;
      }
      // Check to see if Repeater has gone active
      else if ((mic_ptt == LOW) || (cos_in == HIGH)) {
	if (last_id >= CW_TIMEOUT) {
	  state = ID_FIRST;
	  last_id = 0;
	}
	else
	  state = RPTR_ACTIVE;
      }
      break;

    case ID_FIRST:
      voice_timer = VOICE_TIMEOUT;
      last_state = ID_FIRST;
      if ((mic_ptt == HIGH) && (cos_in == LOW)) {
	sendCWID(msg);
	activity_timer = COS_TIMEOUT;
	state = RPTR_ACTIVE;
	last_id = 0;
      }
      else if (--activity_timer <= 0) {
	Serial.printf("Sending Timeout Msg\n");
	sendCWID(msgTimeout);
	sendCWID(msg);
	activity_timer = COS_TIMEOUT;
	state = RPTR_ACTIVE;
	last_id = 0;
      }
      break;
      
    case RPTR_ACTIVE:
      last_state = RPTR_ACTIVE;
      if ((mic_ptt == HIGH) && (cos_in == LOW)) {
	state = TIMING_CW;
	activity_timer = COS_TIMEOUT;
      }
      else if (--activity_timer <= 0) {
	Serial.printf("Sending Timeout Msg\n");
	sendCWID(msgTimeout);
	activity_timer = COS_TIMEOUT;
      }
      else if (--cw_timer == 0) {
	state = CWID;
      }
      break;

    case CWID:
      Serial.print("CW ID\n");
      last_state = CWID;
      sendCWID(msg);
      last_id = 0;
      state = IDLE;
      break;

    case VOICEID:
      Serial.print("VOICE ID\n");
      last_state = VOICEID;
      sendVoiceID();
      state = IDLE;
      break;

    default:
      break;
    }

  // This counter keeps track of last time we ID'd
  ++last_id;
  
  //
  // Blinky Heartbeat LED
  //
  digitalWrite(LED_HEARTBEAT, LED_ON);

  // wait and repeat
  delay(500);
  
  digitalWrite(LED_HEARTBEAT, LED_OFF);

  // wait and repeat
  delay(400);


  Serial.printf("DEBUG: last state: %s, new state: %s, cwtmr=%d, atmr=%d, vtmr=%d, last_id: %d\n", dState[last_state], dState[state], cw_timer, activity_timer, voice_timer, last_id);
}

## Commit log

2017-06-02 1. Re-aligned lower right hole to match lower left 2. Locked all holes, LED's and switches 3. Added bit more clearance in DRC rules 4. Reset trace widths to .024 5. DRC rules checks passing except fo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
    [TeensyCtrlr.brd]
2017-06-02 1. Forgot to reverse LED 1, same position, re-locked it 2. Fixed few trace alignments and un-routed grounds
    [TeensyCtrlr.brd]
2017-06-03 Checkin of faceplate Sketchup files and Simplify 3D printing profile (not yet updated for latest version)
2017-06-11 Add 0.9.2 revised version: - deepen embossed text (also change print settings to print the first 3 layers at 0-.2mm Z resolution) - move right side faceplate mounting holes to the left by 0.5mm
2017-06-11 Add Simplify 3D factory file: print first 4 layers at 0.2 to improve embedded text resolution, then switch to 0.4mm layers for the remainder of the print
2017-06-14 0.9.3 changes: 1. move speaker down to clear the card support rail 2. move the standoffs for the PCB down a bit to add clearance between the speaker and the board (not needed, but just in case ...)
    [westel faceplate 0.9.3.stl]
2017-07-03 Minor layout change (no holes/dimension changes) Generated Gerber files for test run at Seeed Studio Generated some .ps files Top and Bot layers for in house board generation
    [TeensyCtrlr.GBL, TeensyCtrlr.GBO, TeensyCtrlr.GBP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]
2017-07-20 Updated board files for Seeed Fusion board run. Please note that the Voice ID chip layout is totally wrong. Prototype required dead-bug fix with ~27 wires. Will push a fix to the board layout in abou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
    [TeensyCtrlr.brd, TeensyCtrlr.sch]
2017-07-21 Remove old files and replace with (hopefully) final Sketchup, STL, and Simplify 3D factory files
    [westel faceplate 0.9.3.stl, westel faceplate 0.9.4.skp, westel faceplate 0.9.4.stl]
2017-08-10 Initial version deployed on Mingus. There's still a bug that exists where CWID will generate a double ID. Believe due to not waiting 10m after going into IDLE state as next COR causes change into ID_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
    [k7yca.ino]
2017-08-10 Fixed double ID problem by not entering ID_FIRST state from IDLE unless last_id timer has exceeded the CW or Voice ID timer. Tested in Ham mode but still needs to be checked in Commercial mode.
    Cleaned up comments and references.
    [k7yca.ino]

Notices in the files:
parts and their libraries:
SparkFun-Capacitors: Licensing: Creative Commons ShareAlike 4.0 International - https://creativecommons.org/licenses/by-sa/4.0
